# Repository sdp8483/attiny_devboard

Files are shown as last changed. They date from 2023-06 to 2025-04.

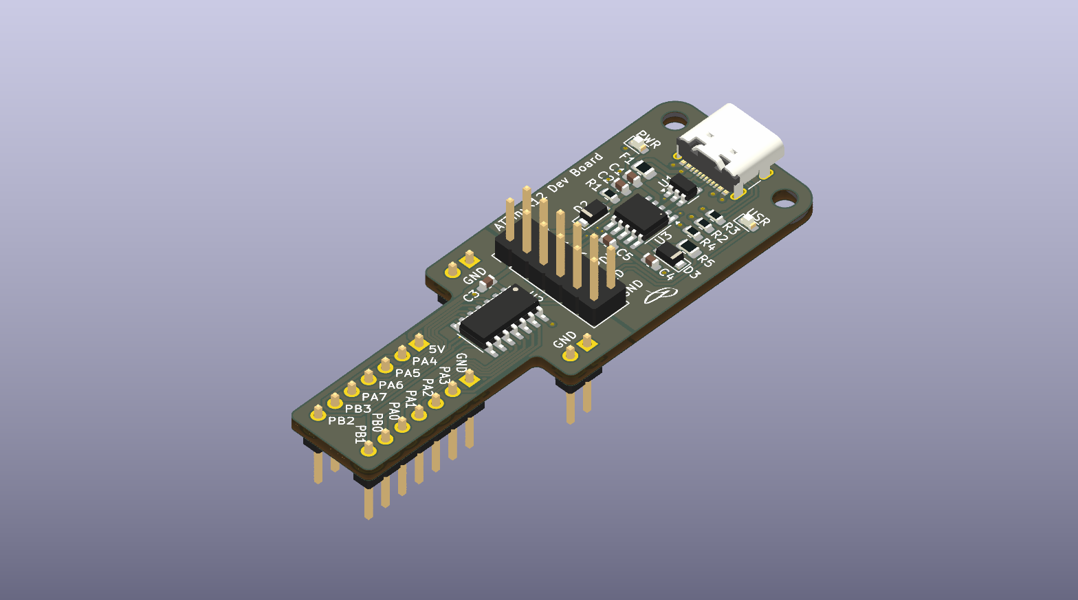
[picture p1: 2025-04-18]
pcb/attinyx14/pcb_render/attinyx14_dev.png

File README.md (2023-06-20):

# Basic Project Template

Directory structure for starting a basic project. 
Originally based off Hackaday article: https://hackaday.com/2017/05/18/kicad-best-practises-library-management/

## Directory Outline
- [`~/firmware/`](firmware): firmware source code and binaries.
- [`~/mechanical/`](mechanical): mechanical CAD design files, for example the enclosure.
    - [`~/mechanical/3d_files/`](mechanical/3d_files): files exported from CAD for import into 3D printer slicing software.
- [`~/pcb/`](pcb): KiCAD design files. When starting a new KiCAD project in this directory be sure to uncheck *Create a new directory for the project* in the **Create New Project** window.
    - [`/pcb/3d_models`](pcb/3d_models)

## Test

```bash
.
├── firmware
├── LICENSE
├── mechanical
│   └── 3d_files
├── pcb
│   ├── 3d_models
│   │   └── README.md
│   ├── bom
│   │   └── README.md
│   ├── datasheets
│   │   └── README.md
│   ├── gerber
│   │   └── README.md
│   ├── images
│   │   └── README.md
│   ├── lib_fp
│   │   ├── bb_logo.pretty
│   │   │   ├── BB_logo_HxW_4x7.5mm.kicad_mod
│   │   │   ├── BB_logo_HxW_5x9.4mm.kicad_mod
│   │   │   ├── BB_logo_HxW_6x11.3mm.kicad_mod
│   │   │   ├── BlueBirdLogo.png
│   │   │   └── BlueBirdLogo.xcf
│   │   ├── pl_logo.pretty
│   │   │   ├── logo_height_10mm.kicad_mod
│   │   │   ├── logo_height_15mm.kicad_mod
│   │   │   ├── logo_height_20mm.kicad_mod
│   │   │   ├── logo_height_3mm.kicad_mod
│   │   │   ├── logo_height_4mm.kicad_mod
│   │   │   ├── logo_height_5mm.kicad_mod
│   │   │   ├── logo_height_6mm.kicad_mod
│   │   │   ├── logo_height_7mm.kicad_mod
│   │   │   ├── logo_height_8mm.kicad_mod
│   │   │   └── logo_height_9mm.kicad_mod
│   │   └── README.md
│   ├── lib_sch
│   │   └── README.md
│   ├── page_layout
│   │   ├── pl_logo.kicad_wks
│   │   ├── pl_page_layout.kicad_wks
│   │   └── README.md
│   ├── pcb_render
│   │   └── README.md
│   └── schematic_pdf
│       └── README.md
└── README.md
```

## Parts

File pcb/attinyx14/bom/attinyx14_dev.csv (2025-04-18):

Ref | Value | MPN | Power | SPN | Supplier | Tolerance | Voltage | Qty | Manufacturer
C1,C3,C5 | 1u | FS18F105Z160PBG |  | C363560 | LCSC |  | 16V | 3
C2,C4 | 100nF | CL10B104KO8NNNC |  | C66501 | LCSC |  | 16V | 2
D1,D4 | LED | NCD0603R1 | 25mA | C84263 | LCSC |  | 1.6V-2.6V | 2
D2,D3 | PMEG6020ER | PMEG6020ER,115 | 2A | C98663 | LCSC |  | 60V | 2
F1 | Polyfuse | MF-PSMF075X-2 | 750mA | C116173 | LCSC |  | 6V | 1
J1 | USB_C_Receptacle_USB2.0_16P | GT-USB-7010ASV | 3A | C2988369 | LCSC |  | 24V | 1
J2,J3 | Conn_01x07 | IPCP254M07PB08V | 3A | C22438422 | LCSC |  |  | 2
J4 | Conn_02x06 | IPCP254M12PB28V | 3A | C22438442 | LCSC |  |  | 1
J5,J6 | Conn_01x02 | IPCP254M02PB08V | 3A | C22395601 | LCSC |  |  | 2
R1,R4 | 1k | RC1608J102CS | 100mW | 1276-5062-1-ND | DigiKey | 5% |  | 2
R2,R3 | 5k1 | RC0603FR-075K1L | 100mW | C105580 | LCSC | 1% |  | 2
R5 | 470 | RC0805FR-07470RL | 125mW | 311-470CRCT-ND | DigiKey | 1% |  | 1
U1 | USBLC6-2SC6 | USBLC6-2SC6 | 5A | C7519 | LCSC |  | 17V 6V | 1
U2 | ATtiny214-SS |  |  |  |  |  |  | 1
U3 | CH342K | CH342K |  | C2826608 | LCSC |  |  | 1

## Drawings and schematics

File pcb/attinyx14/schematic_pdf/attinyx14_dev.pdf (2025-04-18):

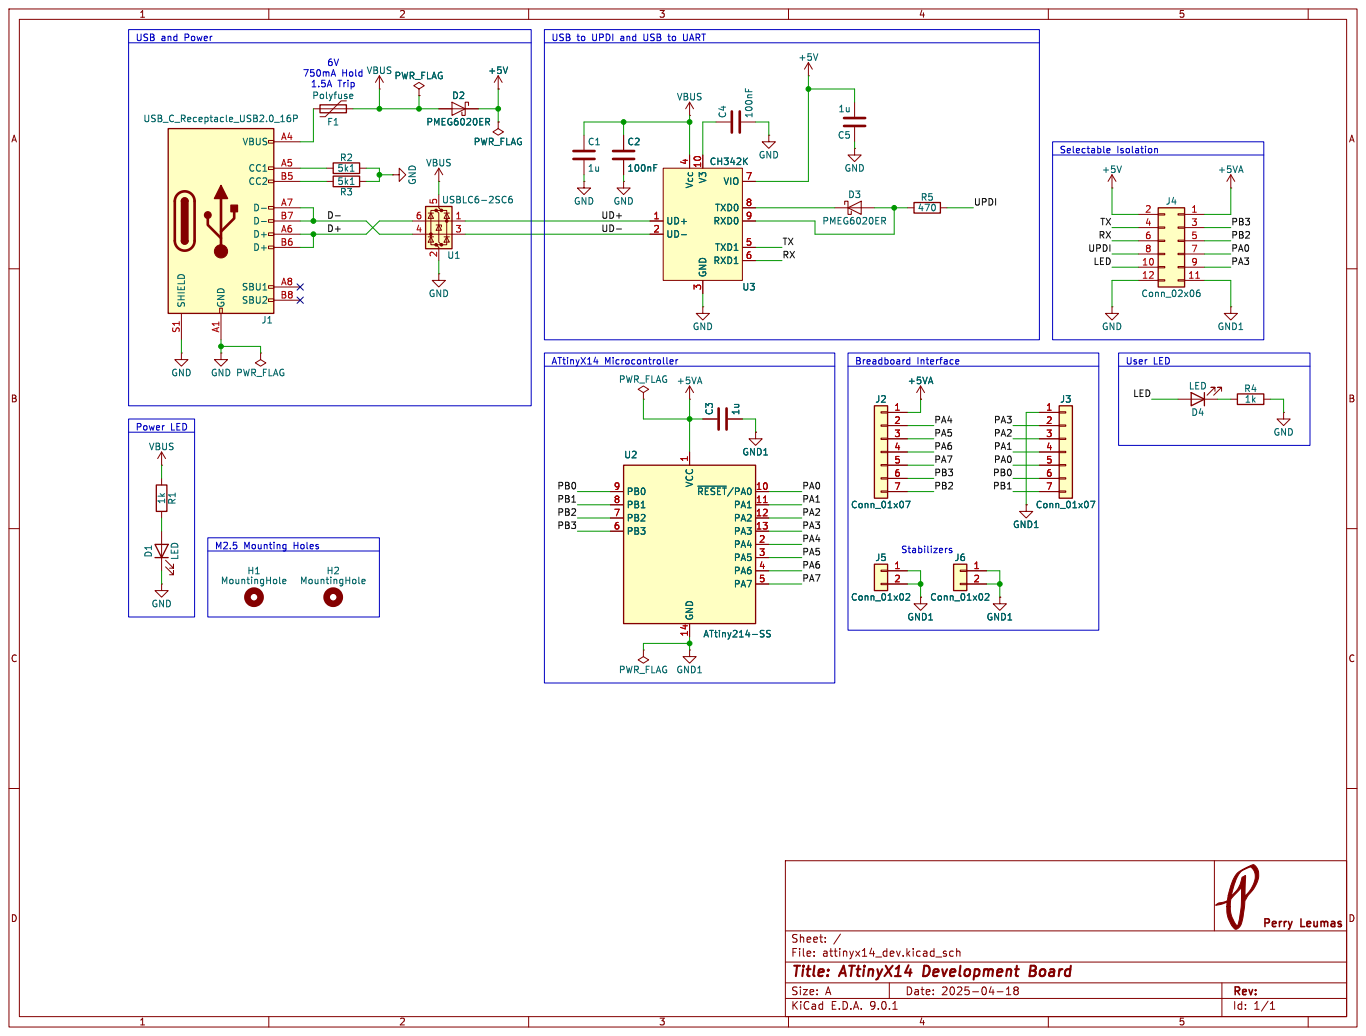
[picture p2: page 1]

Id: 1/1 Title: ATtinyX14 Development Board

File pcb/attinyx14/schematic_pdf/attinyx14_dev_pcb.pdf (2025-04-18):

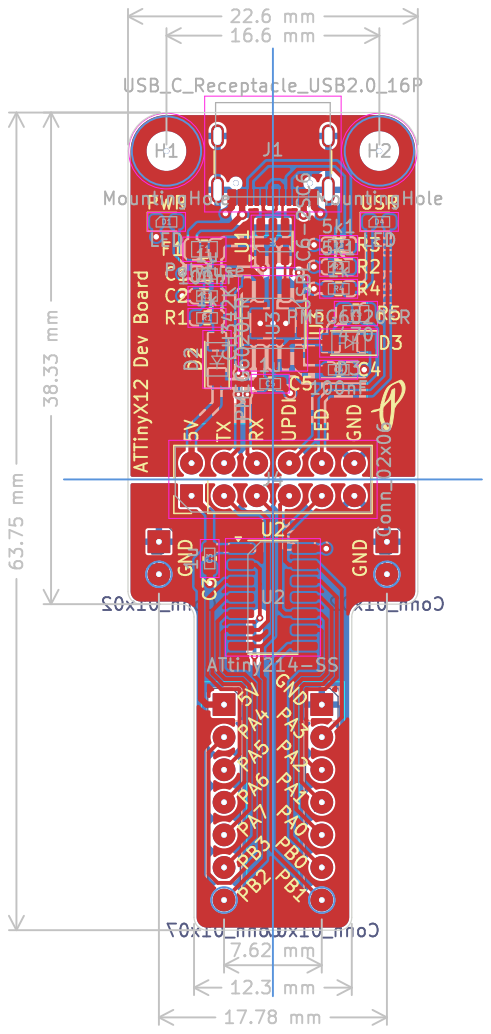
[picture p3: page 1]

Id: 1/1 Title: ATtinyX14 Development Board

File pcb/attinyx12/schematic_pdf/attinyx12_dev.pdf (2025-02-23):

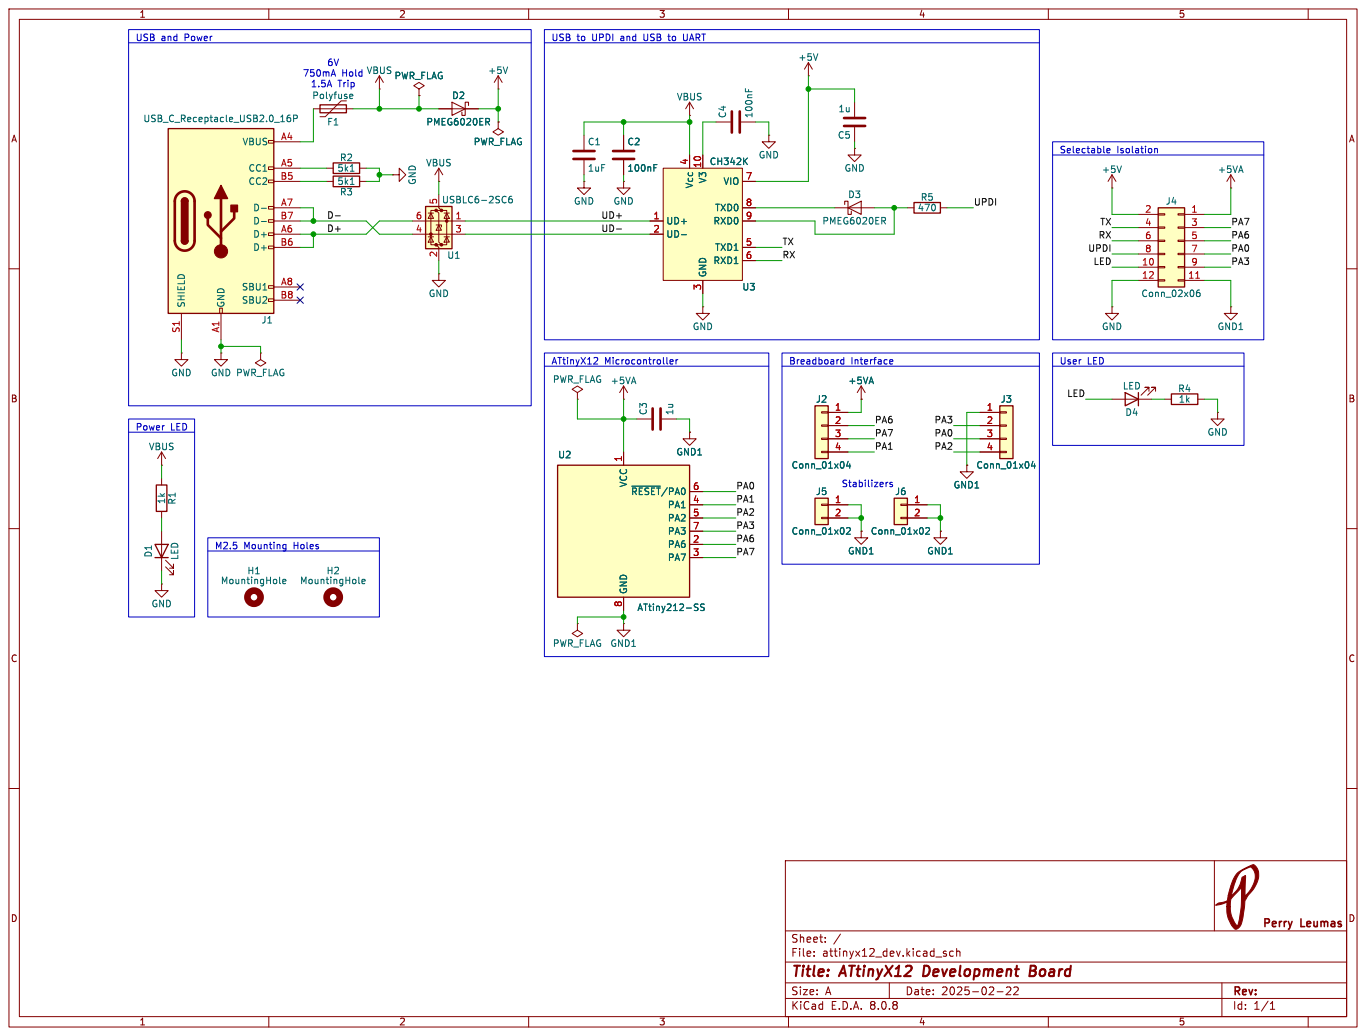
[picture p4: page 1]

Id: 1/1 Title: ATtinyX12 Development Board

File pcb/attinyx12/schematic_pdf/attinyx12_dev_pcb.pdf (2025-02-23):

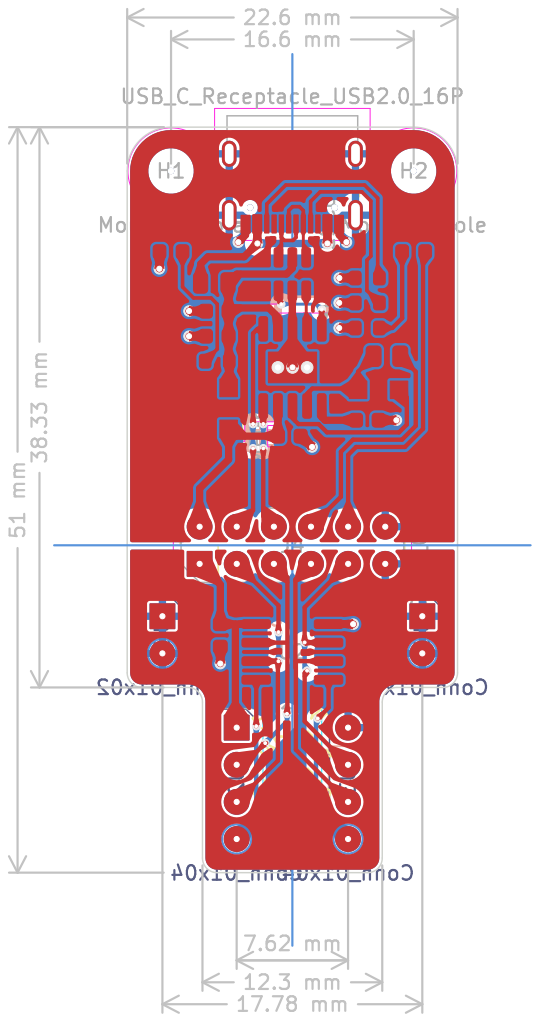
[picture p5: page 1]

Id: 1/1 Title: ATtinyX12 Development Board

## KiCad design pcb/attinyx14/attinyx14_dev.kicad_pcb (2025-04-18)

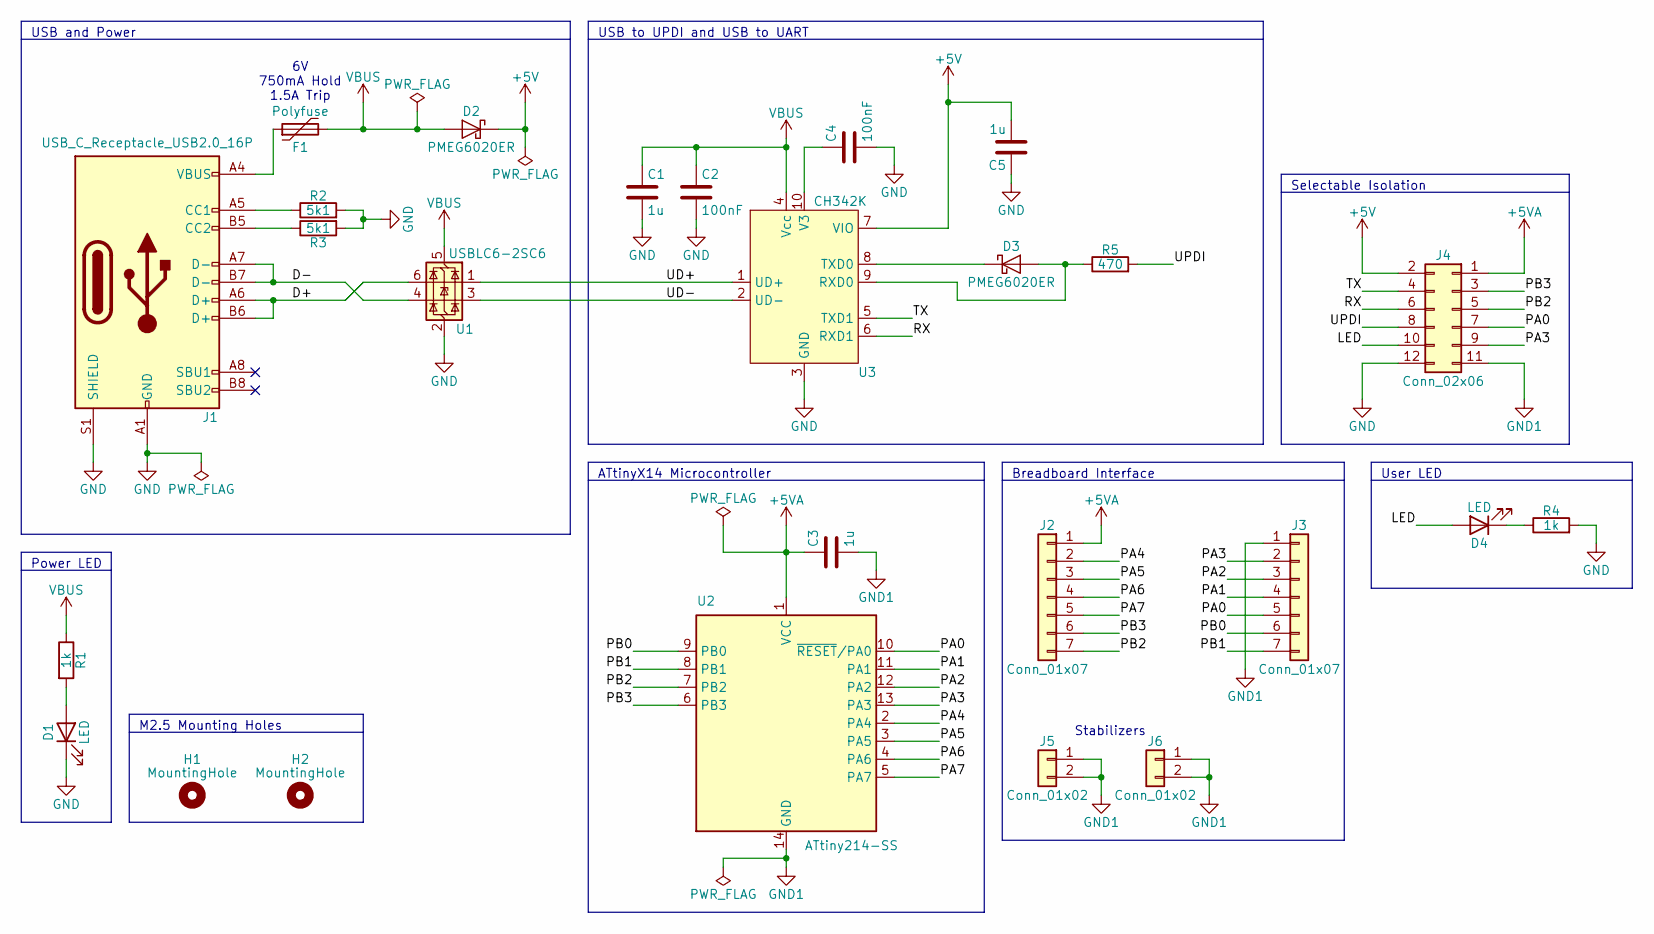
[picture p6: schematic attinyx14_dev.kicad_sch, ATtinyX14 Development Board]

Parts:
C1, C3, C5: 1u; C_0603_1608Metric; Voltage 16V; MPN FS18F105Z160PBG
C2, C4: 100nF; C_0603_1608Metric; Voltage 16V; MPN CL10B104KO8NNNC
D1, D4: LED; LED_0603_1608Metric; Voltage 1.6V-2.6V; MPN NCD0603R1
D2, D3: PMEG6020ER; Nexperia_CFP3_SOD-123W; Voltage 60V; MPN PMEG6020ER,115
F1: Polyfuse; Fuse_0805_2012Metric; Voltage 6V; MPN MF-PSMF075X-2
H1, H2: MountingHole; MountingHole_2.7mm_M2.5
J1: USB_C_Receptacle_USB2.0_16P; USB_C_Receptacle_G-Switch_GT-USB-7010ASV; Voltage 24V; MPN GT-USB-7010ASV
J2, J3: Conn_01x07; PinHeader_1x07_P2.54mm_Vertical; MPN IPCP254M07PB08V
J4: Conn_02x06; PinHeader_2x06_P2.54mm_Vertical; MPN IPCP254M12PB28V
J5, J6: Conn_01x02; PinHeader_1x02_P2.54mm_Vertical; MPN IPCP254M02PB08V
R1, R4: 1k; R_0603_1608Metric; Tolerance 5%; MPN RC1608J102CS
R2, R3: 5k1; R_0603_1608Metric; Tolerance 1%; MPN RC0603FR-075K1L
R5: 470; R_0805_2012Metric; Tolerance 1%; MPN RC0805FR-07470RL
U1: USBLC6-2SC6; SOT-23-6; Voltage 17V 6V; MPN USBLC6-2SC6
U2: ATtiny214-SS; SOIC-14_3.9x8.7mm_P1.27mm
U3: CH342K; SSOP-10-1EP_3.9x4.9mm_P1mm_EP2.1x3.3mm; MPN CH342K

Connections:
+5V: C5.2, D2.1 (K), J4.2, U3.7 (VIO)
+5VA: C3.1, J2.1, J4.1, U2.1 (VCC)
/D+: J1.A6 (D+), J1.B6 (D+), U1.6 (I/O1)
/D-: J1.A7 (D-), J1.B7 (D-), U1.4 (I/O2)
/LED: D4.2 (A), J4.10
/PA0: J3.5, J4.7, U2.10 (~RESET/PA0)
/PA1: J3.4, U2.11 (PA1)
/PA2: J3.3, U2.12 (PA2)
/PA3: J3.2, J4.9, U2.13 (PA3)
/PA4: J2.2, U2.2 (PA4)
/PA5: J2.3, U2.3 (PA5)
/PA6: J2.4, U2.4 (PA6)
/PA7: J2.5, U2.5 (PA7)
/PB0: J3.6, U2.9 (PB0)
/PB1: J3.7, U2.8 (PB1)
/PB2: J2.7, J4.5, U2.7 (PB2)
/PB3: J2.6, J4.3, U2.6 (PB3)
/RX: J4.6, U3.6 (RXD1)
/TX: J4.4, U3.5 (TXD1)
/UD+: U1.1 (I/O1), U3.1 (UD+)
/UD-: U1.3 (I/O2), U3.2 (UD-)
/UPDI: J4.8, R5.2
GND: C1.2, C2.2, C4.2, C5.1, D1.1 (K), J1.A1 (GND), J1.A12 (GND), J1.B1 (GND), J1.B12 (GND), J1.S1 (SHIELD), J4.12, R2.2, R3.2, R4.2, U1.2 (GND), U3.3 (GND), U3.11 (GND)
GND1: C3.2, J3.1, J4.11, J5.1, J5.2, J6.1, J6.2, U2.14 (GND)
unnamed: D1.2 (A), R1.2
unnamed: D3.2 (A), R5.1, U3.9 (RXD0)
unnamed: D3.1 (K), U3.8 (TXD0)
unnamed: D4.1 (K), R4.1
unnamed: F1.1, J1.A4 (VBUS), J1.A9 (VBUS), J1.B4 (VBUS), J1.B9 (VBUS)
unnamed: J1.A5 (CC1), R2.1
unnamed: J1.B5 (CC2), R3.1
unnamed: C4.1, U3.10 (V3)
VBUS: C1.1, C2.1, D2.2 (A), F1.2, R1.1, U1.5 (VBUS), U3.4 (Vcc)

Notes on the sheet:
Power LED
Selectable Isolation
ATtinyX14 Microcontroller
M2.5 Mounting Holes
USB to UPDI and USB to UART
Breadboard Interface
Stabilizers
User LED
USB and Power
6V 750mA Hold 1.5A Trip

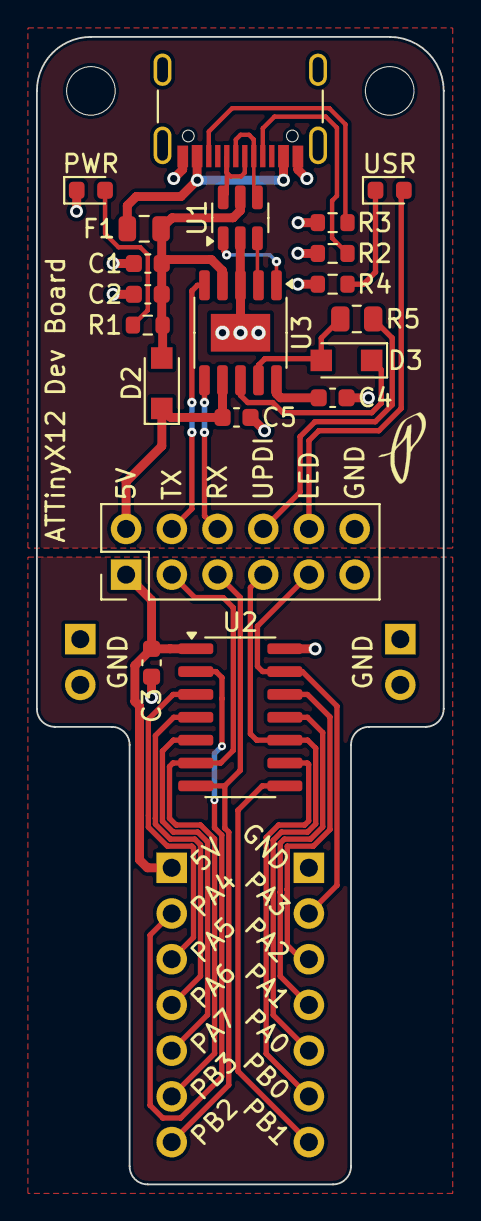
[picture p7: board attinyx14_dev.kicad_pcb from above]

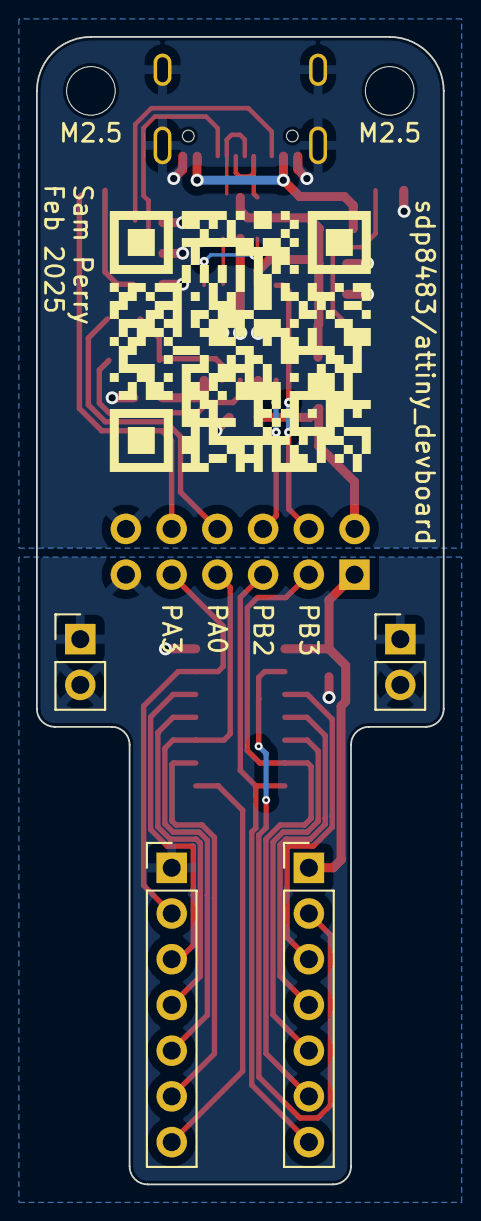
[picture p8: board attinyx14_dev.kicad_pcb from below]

Board: 2 copper layers, 22.6 x 63.8 mm, 27 parts (5 on the bottom side), 33 nets.

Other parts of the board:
QR*****: https://github.com/sdp8483/attiny_devboard; Github QR Code

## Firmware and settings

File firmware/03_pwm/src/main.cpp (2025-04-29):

/* Includes ------------------------------------------------------------------ */
#include <avr/io.h>
#include <avr/delay.h>
#include <stdint.h>

#include "clock.h"  /* set main clock frequency using platformio.ini fcpu value */
#include "usart.h"  /* arduino like Serial print */

/* Define -------------------------------------------------------------------- */
#define LED_PORT        PORTA
#define LED_PIN         PIN3_bm 

#define BLINK_DELAY_ms  500

#define PWM_PER         1024

/* Macro --------------------------------------------------------------------- */

/* Typedef ------------------------------------------------------------------- */

/* Global -------------------------------------------------------------------- */

/* Function Prototypes ------------------------------------------------------- */

/* Main ---------------------------------------------------------------------- */
int main(void) {
    /* setup main clock frequency */
    clock_init();

    /* setup LED pin */
    LED_PORT.OUTCLR = LED_PIN;
    LED_PORT.DIRSET = LED_PIN;

    /* setup TCA0 */
    TCA0.SINGLE.CTRLA |= (TCA_SINGLE_CLKSEL_DIV1_gc | TCA_SINGLE_ENABLE_bm);
    TCA0.SINGLE.CTRLB |= (TCA_SINGLE_CMP0_bm | TCA_SINGLE_WGMODE_SINGLESLOPE_gc);
    TCA0.SINGLE.PER = PWM_PER;
    TCA0.SINGLE.CMP0 = 0;

    /* setup uart */
    Serial.begin(BAUDRATE); 
    Serial.println("Hello World!");

    while(1) {
        Serial.println("Shine");
        for (int16_t i=100; i<PWM_PER; i+=10) {
            TCA0.SINGLE.CMP0 = i;
            _delay_ms(10);
        }
        
        Serial.println("Fade");
        for (int16_t i=PWM_PER; i>100; i-=10) {
            TCA0.SINGLE.CMP0 = i;
            _delay_ms(10);
        }
    }
}

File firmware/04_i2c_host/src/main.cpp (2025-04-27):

/* Includes ------------------------------------------------------------------ */
#include <avr/io.h>
#include <avr/delay.h>
#include <stdint.h>

#include "clock.h"      /* set main clock frequency using platformio.ini fcpu value */
#include "usart.h"      /* arduino like Serial print */
#include "i2c.h"        /* i2c host library */

/* Define -------------------------------------------------------------------- */
#define LED_PORT            PORTA
#define LED_PIN             PIN3_bm

#define I2C_CLIENT_ADDRESS  0x38    /* PCF8574A I/O expander */

/* Macro --------------------------------------------------------------------- */

/* Typedef ------------------------------------------------------------------- */

/* Global -------------------------------------------------------------------- */

/* Function Prototypes ------------------------------------------------------- */

/* Main ---------------------------------------------------------------------- */
int main(void) {
    /* setup main clock frequency */
    clock_init();

    /* setup UART for debug printing */
    Serial.begin(BAUDRATE);

    /* setup LED pin */
    LED_PORT.OUTCLR = LED_PIN;
    LED_PORT.DIRSET = LED_PIN;

    i2c_host.init();

    uint8_t data;

    while(1) {
        LED_PORT.OUTSET = LED_PIN;
        i2c_host.start(I2C_CLIENT_ADDRESS, I2C_HOST::i2c_host_direction::I2C_HOST_WRITE);
        data = 0x7F;
        i2c_host.write(&data);
        i2c_host.stop();

        i2c_host.start(I2C_CLIENT_ADDRESS, I2C_HOST::i2c_host_direction::I2C_HOST_READ);
        i2c_host.read(&data, I2C_HOST::i2c_host_response::I2C_HOST_NACK);
        i2c_host.stop();

        Serial.println(data, HEX);
        _delay_ms(100);

        LED_PORT.OUTCLR = LED_PIN;
        i2c_host.start(I2C_CLIENT_ADDRESS, I2C_HOST::I2C_HOST_WRITE);
        data = 0xFD;
        i2c_host.write(&data);
        i2c_host.stop();

        i2c_host.start(I2C_CLIENT_ADDRESS, I2C_HOST::I2C_HOST_READ);
        i2c_host.read(&data, I2C_HOST::i2c_host_response::I2C_HOST_NACK);
        i2c_host.stop();
        Serial.println(data, HEX);

        _delay_ms(100);
    }
}

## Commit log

2023-06-21 start schma
    [attiny212_dev.kicad_pcb, attiny212_dev.kicad_sch]
2025-01-22 rename kicad project and dir
    [attinyx12_dev.kicad_pcb, attinyx12_dev.kicad_sch]
2025-01-23 schematic update
    [attinyx12_dev.kicad_sch]
2025-01-24 create switch 3d model
2025-01-24 schema done
    [attinyx12_dev.kicad_sch]
2025-02-06 add mounting holes
    [attinyx12_dev.kicad_sch]
2025-02-08 reduce mounting holes to 2.5mm
    [attinyx12_dev.kicad_sch]
2025-02-08 replace switch with jumpers, remove buttons
    [attinyx12_dev.kicad_sch]
2025-02-13 polyfuse and TVS+ESD for USB
    [attinyx12_dev.kicad_sch]
2025-02-13 add power indicator LED
    [attinyx12_dev.kicad_sch]
2025-02-13 TI Launchpad style isolation from programmer
    [attinyx12_dev.kicad_sch]
2025-02-13 cleanup UPDI section
    [attinyx12_dev.kicad_sch]
2025-02-13 flip isolation connector
    [attinyx12_dev.kicad_sch]
2025-02-16 remove 2 mounting holes
    [attinyx12_dev.kicad_sch]
2025-02-16 layout programmer side
    [attinyx12_dev.kicad_pcb]
2025-02-17 almost there
    [attinyx12_dev.kicad_pcb]
2025-02-17 user LED on programmer side
    [attinyx12_dev.kicad_pcb, attinyx12_dev.kicad_sch]
2025-02-21 rearrange layout
    [attinyx12_dev.kicad_pcb]
2025-02-22 add from cimos/Kicad-CustomDesignRules
2025-02-22 final layout
    [attinyx12_dev.kicad_pcb, attinyx12_dev.kicad_sch]
2025-02-22 add silkscreen
    [attinyx12_dev.kicad_pcb, attinyx12_dev.kicad_sch]
2025-02-23 add dimensions
    [attinyx12_dev.kicad_pcb]
2025-02-23 export from kicad
    [attinyx12_dev-B_Cu.gbl, attinyx12_dev-B_Mask.gbs, attinyx12_dev-B_Paste.gbp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]
2025-02-23 adjustments after DFM analysis
    [attinyx12_dev-B_Cu.gbl, attinyx12_dev-B_Mask.gbs, attinyx12_dev-B_Paste.gbp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]
2025-02-23 update components with MPN, SPN, etc
    [attinyx12_dev.kicad_sch]
2025-03-13 create uart hello world
2025-03-13 rename LED define
2025-03-13 error using BAUD, change to BAUDRATE
    [main.cpp]
2025-03-16 create pwm example
2025-04-18 init commit
    [attinyx14_dev.kicad_pcb, attinyx14_dev.kicad_sch]
2025-04-18 pcb layout done
    [attinyx14_dev.kicad_pcb]
2025-04-18 drc check and fix
    [attinyx14_dev.kicad_pcb]
2025-04-18 add datasheet link
    [attinyx14_dev.kicad_sch]
2025-04-18 update 3d model link
    [attinyx14_dev.kicad_pcb]
2025-04-18 export files
    [attinyx14_dev-B_Cu.gbl, attinyx14_dev-B_Mask.gbs, attinyx14_dev-B_Paste.gbp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]
2025-04-22 start i2c lib
2025-04-24 test flow diagram
2025-04-24 start i2c host read/write example
